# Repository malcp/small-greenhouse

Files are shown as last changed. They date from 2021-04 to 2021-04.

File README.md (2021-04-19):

# Small parametric greenhouse
Small greenhouse with four shelves, three of them removable, and a window on the roof that can be built using very basic tools and sized to fit into almost any space.

The full assembly is in draws/Main.FCStd. It also contains the spreadsheet used to define the sizes.

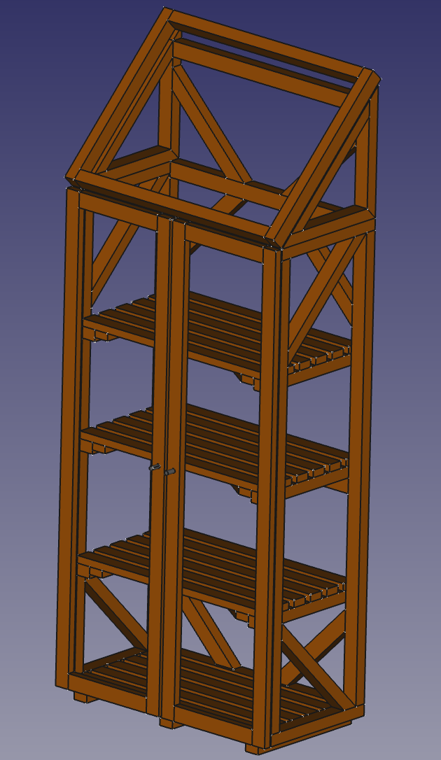
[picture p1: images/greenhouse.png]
Greenhouse pic


## Prerequisites
- [FreeCAD][freecadweb]. Version 0.19 works, but other version could work as well.
- FreeCAD's Assembly2+ addon. v0.4.53 at the moment of writing this document. It can be installed from inside FreeCAD using the Addon Manager.

## Configuration
In order to tweak the size of the greenhouse, follow the below steps:
1. Clone the project: `git clone https://github.com/malcp/small-greenhouse.git`
2. Open the main file with FreeCAD: `draws/Main.FCStd`
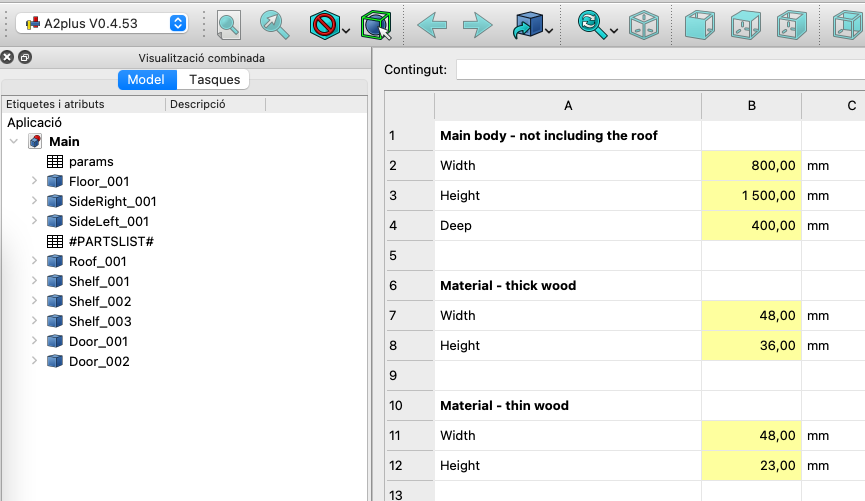
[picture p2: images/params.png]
Parameters pic
3. Open the parameters spreadsheet. It is called `params`. 
5. Set the desired sizes and save the document.
6. Go back to `draws/Main.FCStd` and click to `Update parts imported into the assembly` and then `Update imports recursively`.
7. Finally, update the parts lists.

## Cut lists
https://www.opticutter.com/linear-cut-list-calculator and https://www.opticutter.com/cut-list-optimizer have been used to calculate the amount of wood and plastic boards required for building the greenhouse.

## License
Shield: [][cc-by-sa]

This work is licensed under a
[Creative Commons Attribution-ShareAlike 4.0 International License][cc-by-sa].

[][cc-by-sa]

[cc-by-sa]: http://creativecommons.org/licenses/by-sa/4.0/
[cc-by-sa-image]: https://licensebuttons.net/l/by-sa/4.0/88x31.png
[cc-by-sa-shield]: https://img.shields.io/badge/License-CC%20BY--SA%204.0-lightgrey.svg
[freecadweb]: https://www.freecadweb.org/

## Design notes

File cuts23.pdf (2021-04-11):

Linear Cutting Plan / optiCutter

Layout patterns

Created by www.opticutter.com

Required stocks

Stock length | Quantity
4,200 | 6
Total | 6
Kerf | 3
Total parts | 35
Total parts length | 24,212
Used stocks total length | 25,200
Total yield | 96.08 %
Repetition | Stock length | Cuts | Material waste | Cut waste
3x | 4,200 | [ 5x 704 ] [ 1x 648 ] | 14 | 18
2x | 4,200 | [ 1x 704 ] [ 1x 400 ] [ 2x 1500 ] | 84 | 12
1x | 4,200 | [ 1x 704 ] [ 4x 400 ] [ 4x 299 ] | 673 | 27

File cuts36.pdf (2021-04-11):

Linear Cutting Plan / optiCutter

Layout patterns

Created by www.opticutter.com

Required stocks

Stock length | Quantity
4,200 | 7
Total | 7
Kerf | 3
Total parts | 47
Total parts length | 27,364
Used stocks total length | 29,400
Total yield | 93.07 %
Repetition | Stock length | Cuts | Material waste | Cut waste
1x | 4,200 | [ 1x 400 ] [ 2x 1428 ] [ 2x 464 ] | 1 | 15
1x | 4,200 | [ 2x 1428 ] [ 2x 464 ] [ 1x 400 ] | 1 | 15
1x | 4,200 | [ 2x 464 ] [ 5x 400 ] [ 3x 400 ] | 42 | 30
1x | 4,200 | [ 10x 400 ] | 170 | 30
2x | 4,200 | [ 5x 704 ] [ 1x 400 ] | 262 | 18
1x | 4,200 | [ 1x 400 ] [ 2x 728 ] [ 2x 586 ] | 1,157 | 15

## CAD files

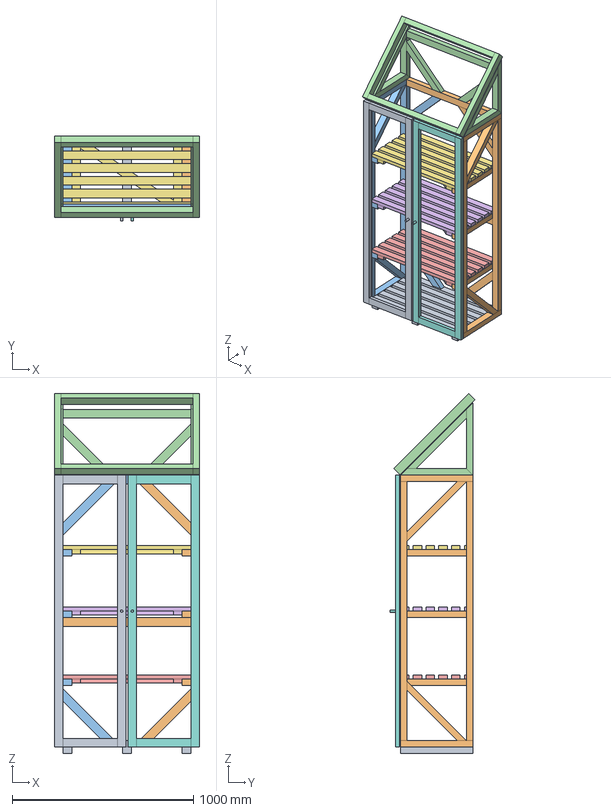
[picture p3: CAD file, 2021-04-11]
draws/Main.FCStd
800.0 x 467.5 x 1986.1 mm
Floor_001
SideRight_001
SideLeft_001
Roof_001
Shelf_001
Shelf_002
Shelf_003
Door_001
Door_002

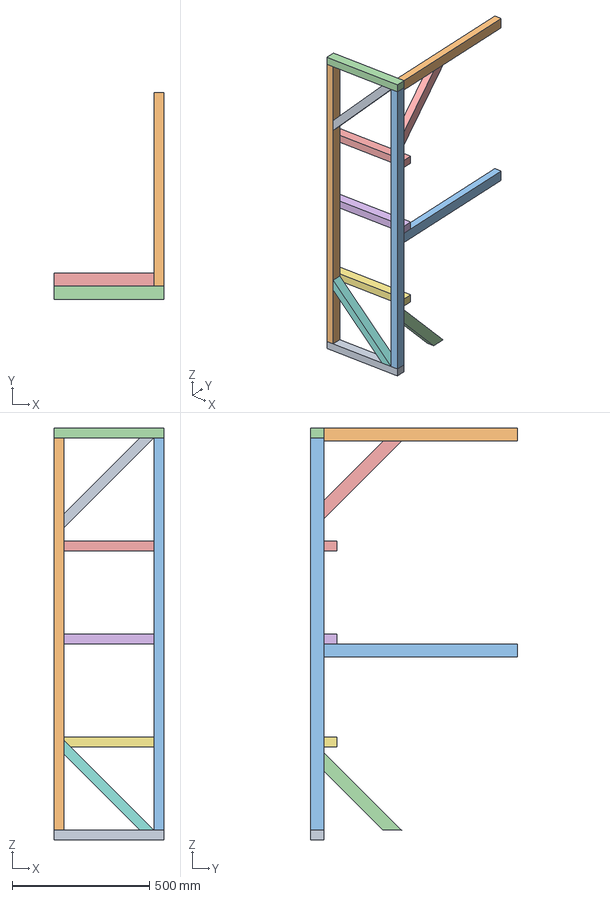
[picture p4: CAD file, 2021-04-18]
draws/SideRight.FCStd
400.0 x 752.0 x 1500.0 mm
floorDeep_004
innerHeight_001
innerHeight_002
floorDeep_005
floorDeep_001
floorDeep_002
floorDeep_003
roofHipotenusa_001
roofHipotenusa_002
floorWidth_001
floorWidth_002
backTorque_001
backTorque_002

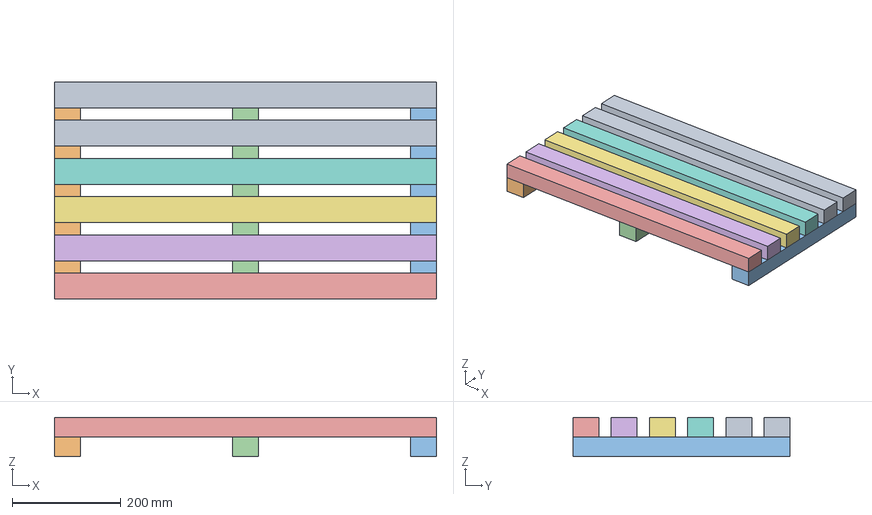
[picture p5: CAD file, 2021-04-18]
draws/Floor.FCStd
704.0 x 400.0 x 72.0 mm
floorWidth_001
floorDeep_001
floorDeep_002
floorDeep_003
floorWidth_002
floorWidth_003
floorWidth_004
floorWidth_005
floorWidth_006

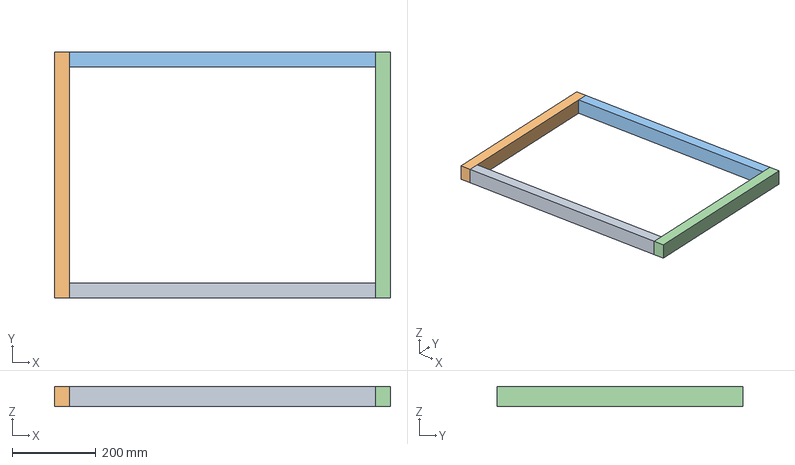
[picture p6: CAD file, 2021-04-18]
draws/Window.FCStd
800.0 x 585.7 x 48.0 mm
windowFrameWidth_001
windowFrameHeight_001
windowFrameWidth_002
windowFrameHeight_002

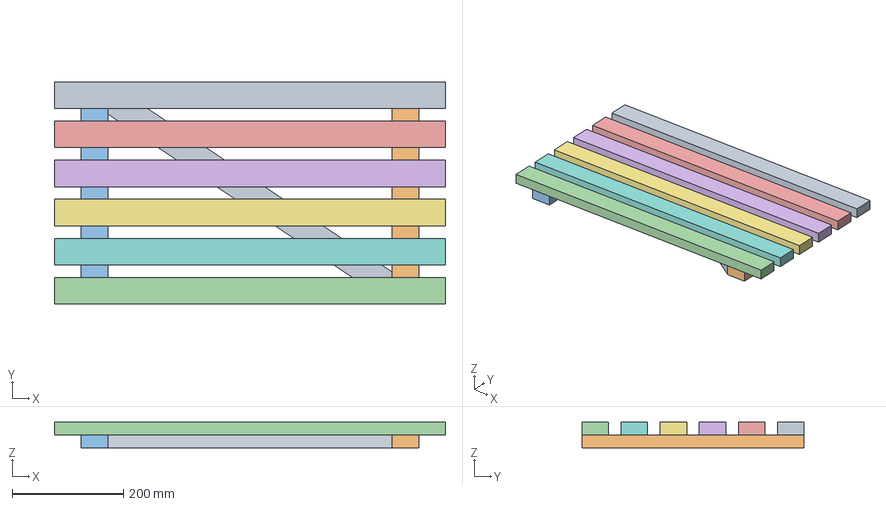
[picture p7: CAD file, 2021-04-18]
draws/Shelf.FCStd
704.0 x 400.0 x 46.0 mm
thinInnerWidth_001
thinOuterDeep_001
thinOuterDeep_002
thinInnerWidth_002
thinInnerWidth_003
thinInnerWidth_004
thinInnerWidth_005
thinInnerWidth_006
shelfZ_001

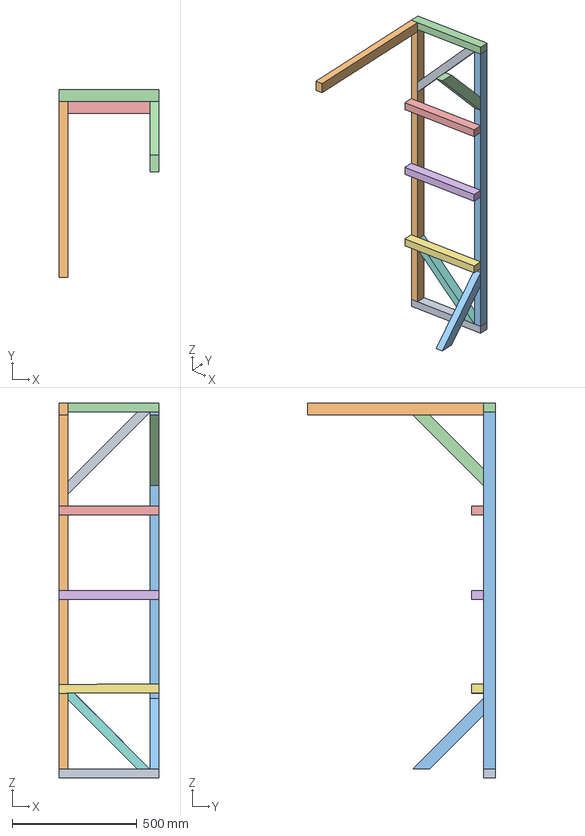
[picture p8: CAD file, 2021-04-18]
draws/SideLeft.FCStd
400.0 x 752.0 x 1500.0 mm
floorDeep_004
innerHeight_001
innerHeight_002
floorDeep_005
floorDeep_001
floorDeep_002
floorDeep_003
roofHipotenusa_001
roofHipotenusa_002
floorWidth_001
backTorque_001
backTorque_002

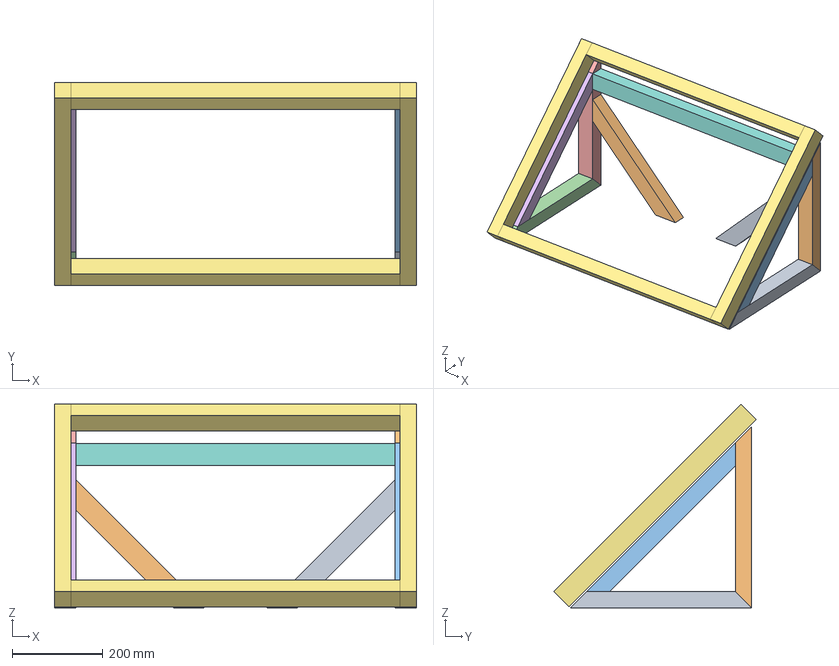
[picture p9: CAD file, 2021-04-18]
draws/Roof.FCStd
800.0 x 448.1 x 450.1 mm
roofBase_001
roofBase_002
roofHipotenusa_001
roofBase_003
roofBase_004
roofHipotenusa_002
Window_001
floorWidth_003
backTorque_005
backTorque_006

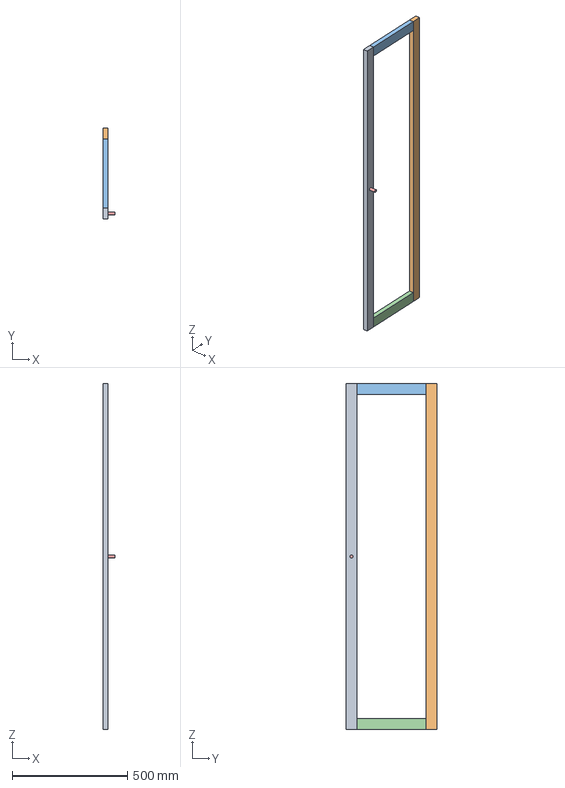
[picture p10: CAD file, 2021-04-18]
draws/Door.FCStd
53.0 x 395.0 x 1500.0 mm
thinDoorFrameHeight_001
thinDoorFrameHeight_002
thinDoorFrameWidth_001
thinDoorFrameWidth_002
doorHandle_001

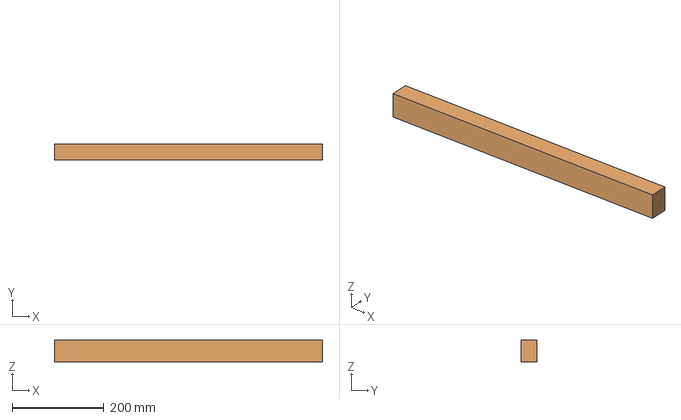
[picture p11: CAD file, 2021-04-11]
draws/windowFrameHeight.FCStd
585.7 x 36.0 x 48.0 mm

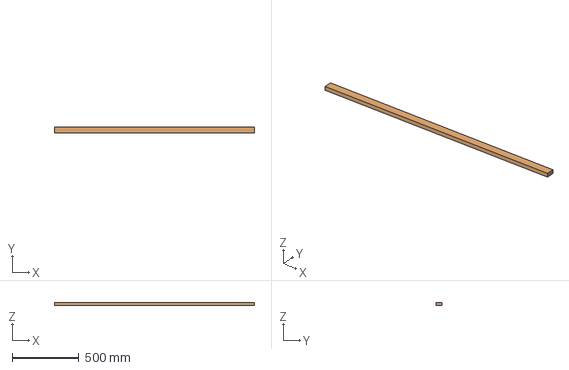
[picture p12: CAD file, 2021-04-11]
draws/thinDoorFrameHeight.FCStd
1500.0 x 48.0 x 23.0 mm

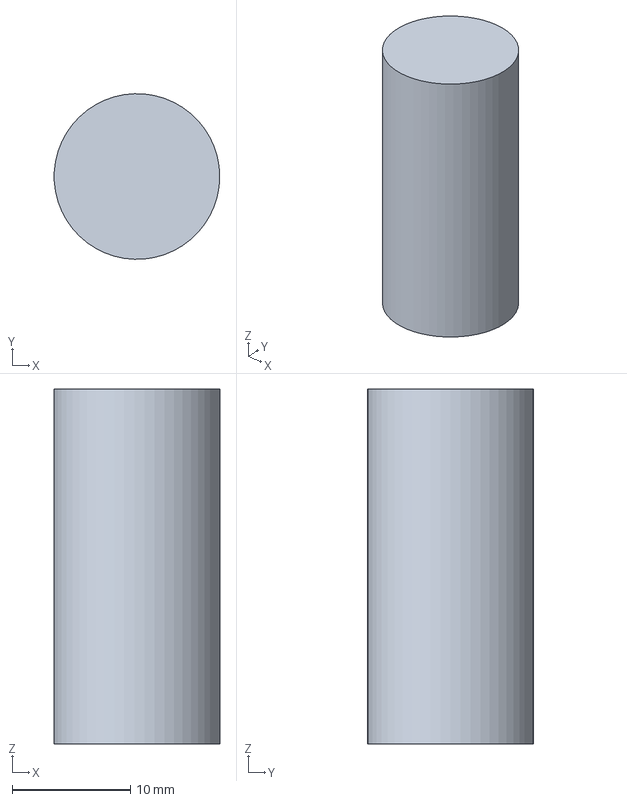
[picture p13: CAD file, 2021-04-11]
draws/doorHandle.FCStd
14.0 x 14.0 x 30.0 mm

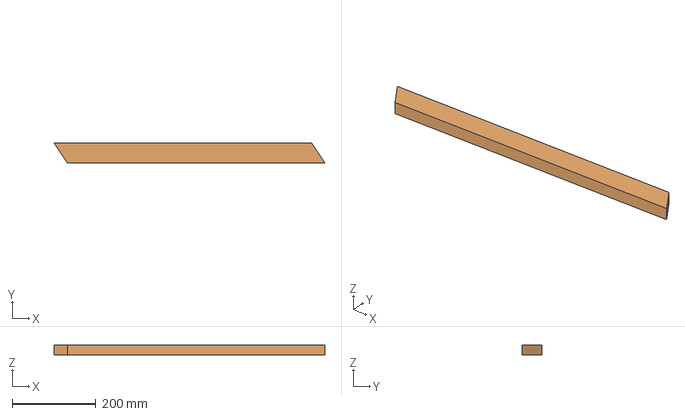
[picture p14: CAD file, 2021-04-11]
draws/shelfZ.FCStd
647.9 x 48.0 x 23.0 mm

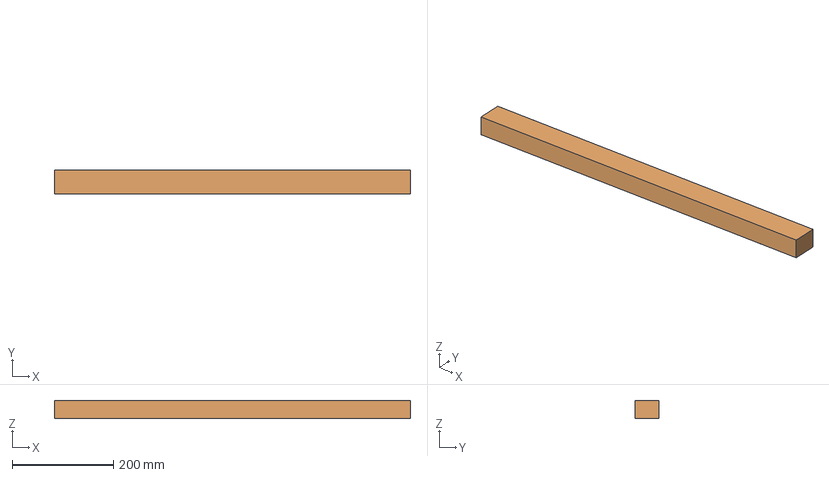
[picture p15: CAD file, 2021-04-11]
draws/floorWidth.FCStd
704.0 x 48.0 x 36.0 mm

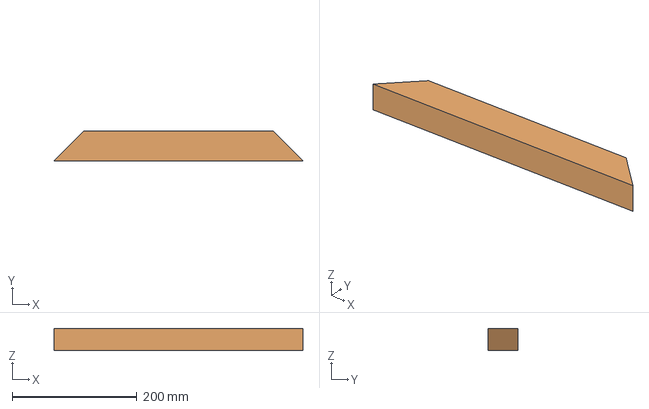
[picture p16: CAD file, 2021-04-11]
draws/backTorque.FCStd
400.0 x 48.0 x 36.0 mm

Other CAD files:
draws/windowFrameWidth.FCStd
draws/innerHeight.FCStd
draws/thinOuterDeep.FCStd
draws/thinInnerWidth.FCStd
draws/floorDeep.FCStd
draws/outerDeep.FCStd
draws/roofBase.FCStd
draws/roofHipotenusa.FCStd
draws/thinDoorFrameWidth.FCStd

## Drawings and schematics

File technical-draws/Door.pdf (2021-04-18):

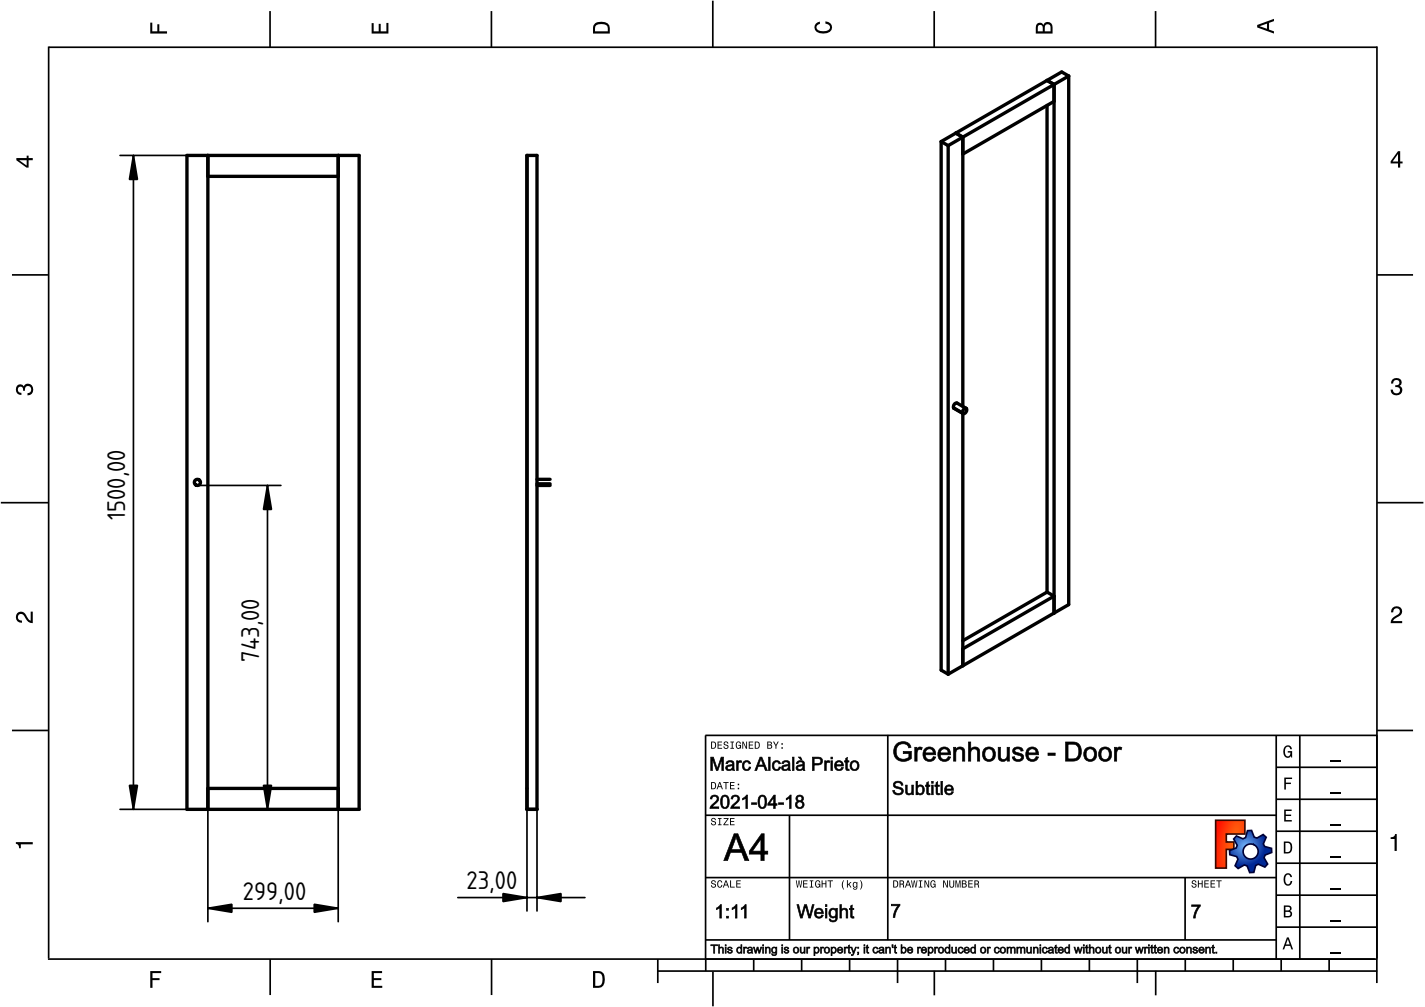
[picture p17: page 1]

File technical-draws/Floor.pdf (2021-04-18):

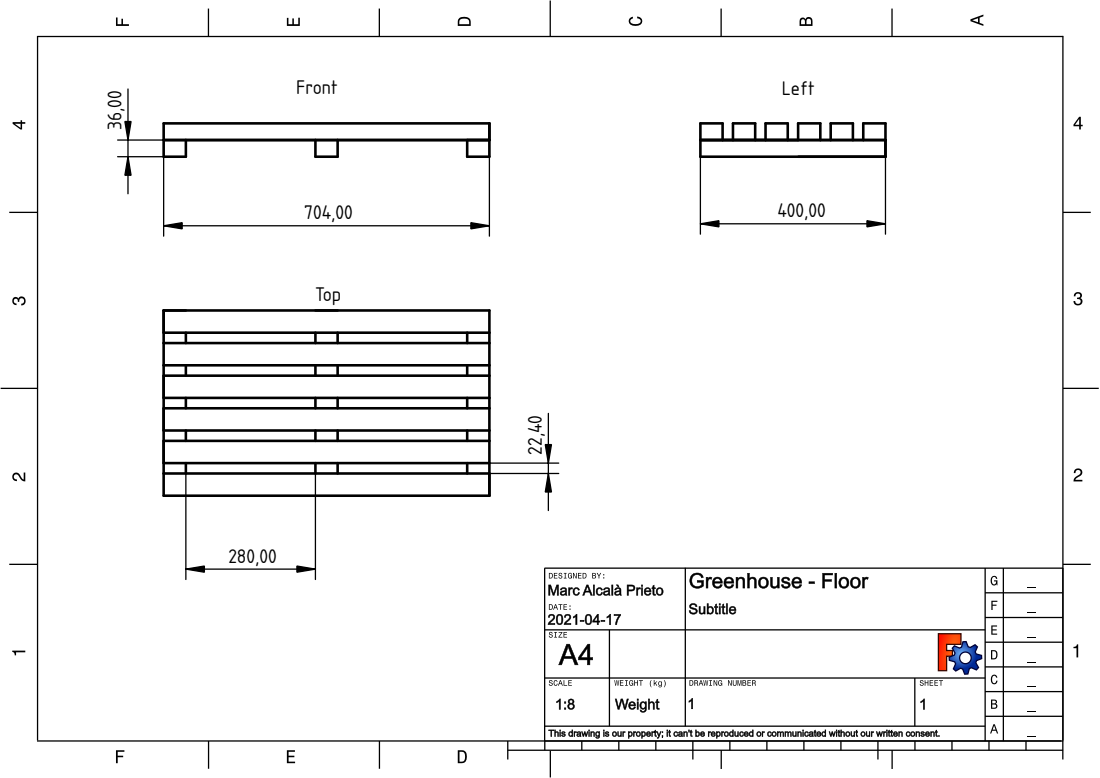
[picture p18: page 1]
Fro; eft Top

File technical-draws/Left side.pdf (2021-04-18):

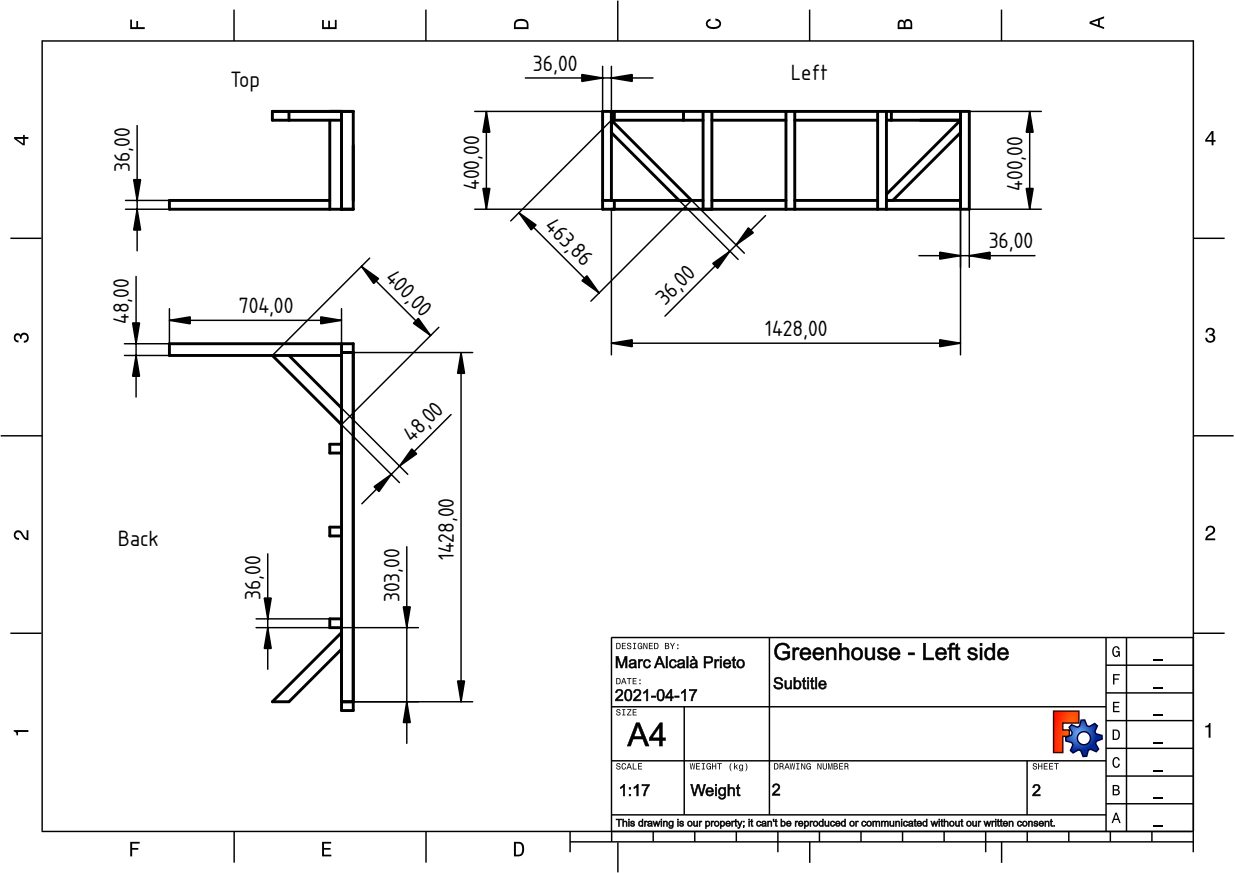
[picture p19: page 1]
eft Back

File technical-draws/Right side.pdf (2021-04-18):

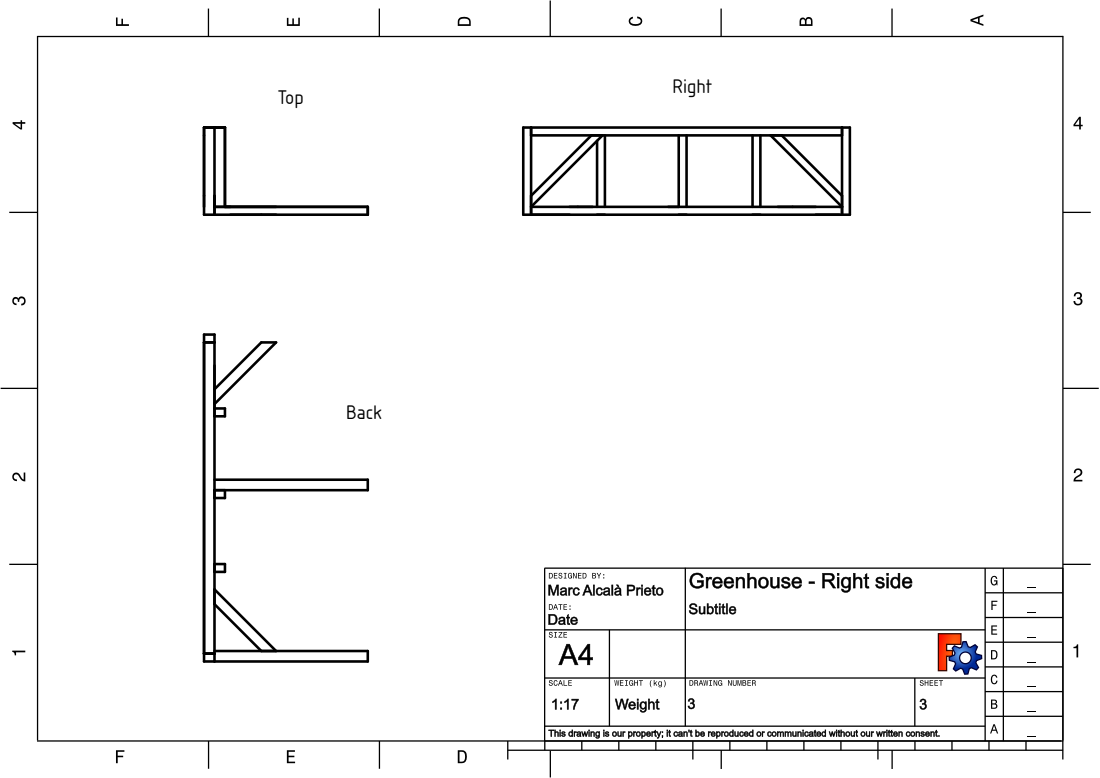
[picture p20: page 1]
Top; Right; Back

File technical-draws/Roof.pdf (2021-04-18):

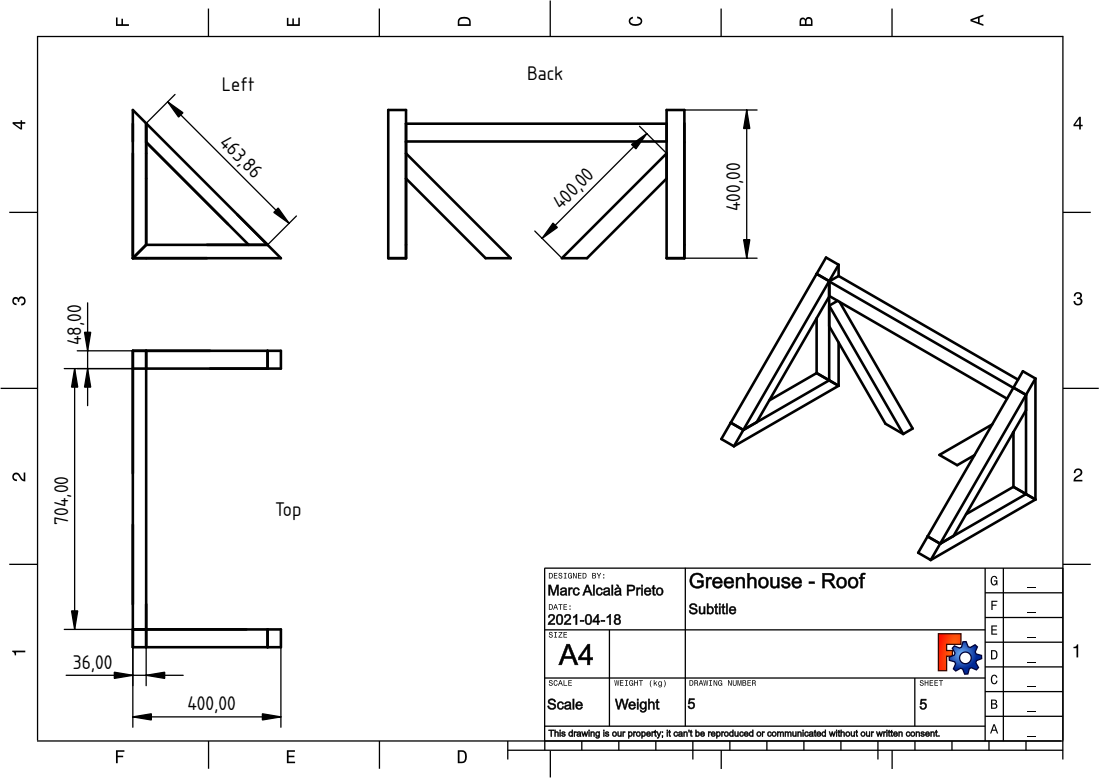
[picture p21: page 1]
eft; ack

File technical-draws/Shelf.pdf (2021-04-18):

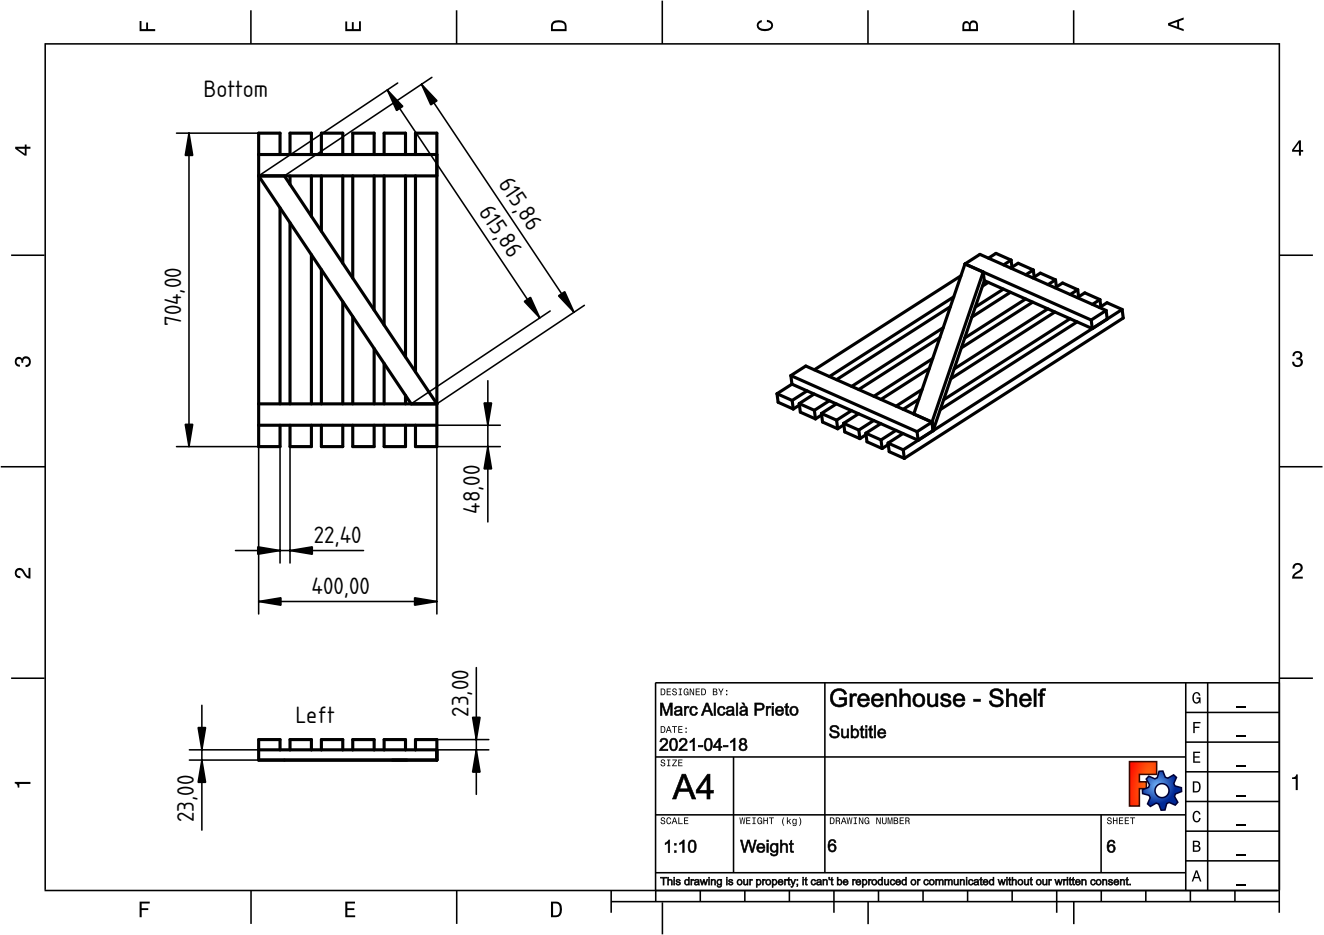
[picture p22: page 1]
Bottom; Left

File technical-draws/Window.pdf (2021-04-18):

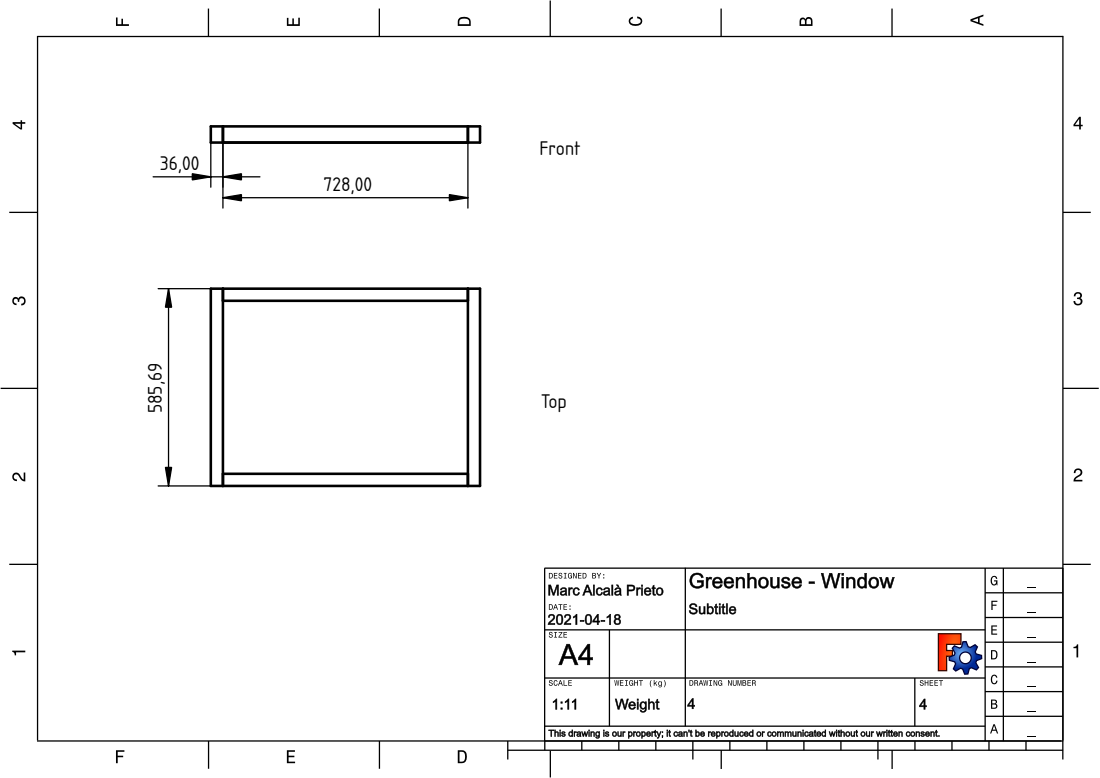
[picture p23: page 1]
Fro

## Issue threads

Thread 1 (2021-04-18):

Please add 'Prerequisite' section

luzpaz, 2021-04-18:
Looks like Assembly2+ is a prerequisite.

malcp, 2021-04-19:
Yes, indeed. Will fix.

malcp, 2021-04-19:
Thanks for reporting it.

malcp, 2021-04-19:
I've added that and also a section explaining how to modify the size of the greenhouse. Closing.

Closed 2021-04-19.

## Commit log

2021-04-04 Fix assembly
    [Door.FCStd, Floor.FCStd, Main.FCStd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]
2021-04-04 Add cuts lists
    [cuts23.csv, cuts36.csv, cutsPlastic.csv]
2021-04-04 Explain which tool has been used to calculate the cut lists
2021-04-04 Assembly the doors and add a picture.
    [Door.FCStd, Floor.FCStd, Main.FCStd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]
2021-04-04 Make the body more robust.
    [Door.FCStd, Floor.FCStd, Main.FCStd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]
2021-04-04 Update cuts
    [Main.FCStd, cuts36.csv]
2021-04-04 Mirror sides
    [Door.FCStd, Floor.FCStd, Main.FCStd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]
2021-04-04 Adjust roof's reinforcement
    [Door.FCStd, Floor.FCStd, Main.FCStd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]
2021-04-04 Parameters explained
    [Door.FCStd, Floor.FCStd, Main.FCStd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]
2021-04-05 Fix door joins
    [Door.FCStd, Floor.FCStd, Main.FCStd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]
2021-04-05 Shelfs are Zs
    [Door.FCStd, Floor.FCStd, Main.FCStd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]
2021-04-11 Use butt joints in doors and roof window
    [Door.FCStd, Floor.FCStd, Main.FCStd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]
2021-04-18 Add technical draws
    [Door.FCStd, Floor.FCStd, Roof.FCStd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]
